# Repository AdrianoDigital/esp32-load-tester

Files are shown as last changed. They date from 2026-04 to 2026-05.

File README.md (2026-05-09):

# esp32-load-tester






A simple, low-cost weight/force measurement device based on an ESP32/ESP8266 and a [load cell](https://en.wikipedia.org/wiki/Load_cell).

It provides:
- A web interface for control and live measurement
- Optional OLED display for local readout
- Simple hardware using inexpensive, widely available components

> ⚠️ Designed for **low-cost, low-accuracy applications** (~±5%, <5 Hz sampling rate)

---

## 📸 Overview

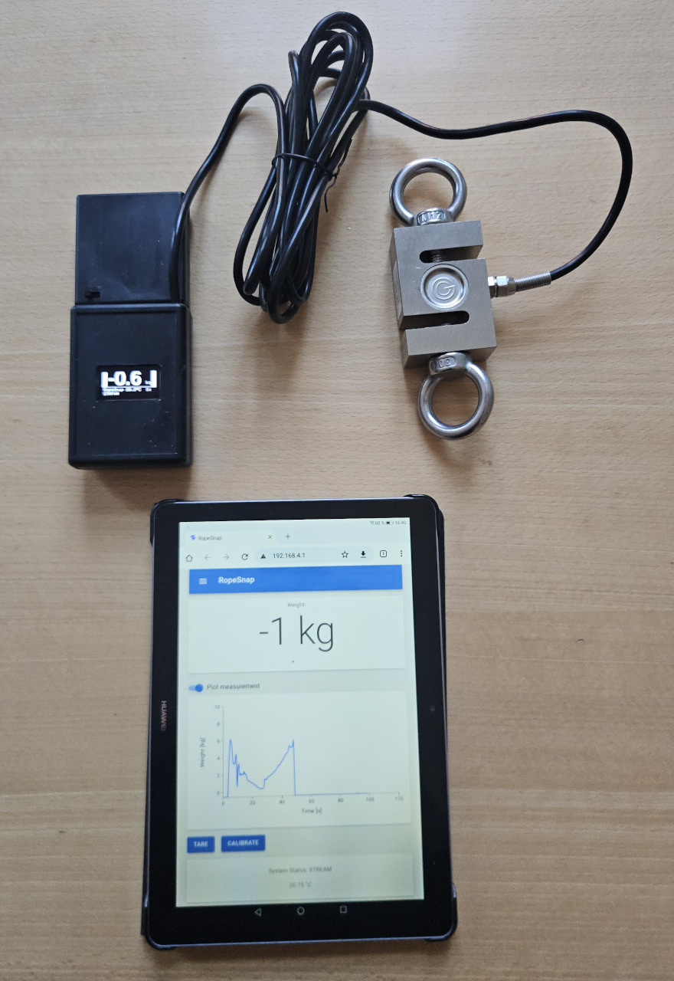
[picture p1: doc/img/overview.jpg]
Device overview


---

## ✨ Features

- Works with a wide range of load cells (grams → tons)
- Wi-Fi access point (no external network required)
- Web-based UI (phone, tablet, desktop)
- Live graph visualization
- QR code for easy connection
- Optional:
  - OLED display
  - Temperature sensor

---

## 🧰 Applications

Suitable for **slow-changing, low-accuracy measurements**, such as:

- Simple tensile strength testing
- Hanging scales
- Simple force measurement

### Example: Tensile Strength Tester

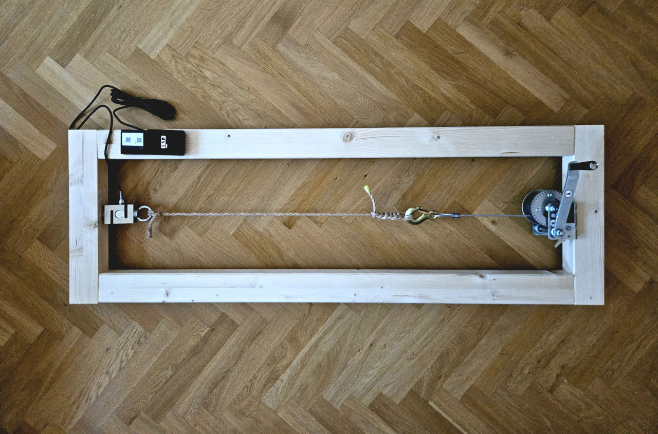
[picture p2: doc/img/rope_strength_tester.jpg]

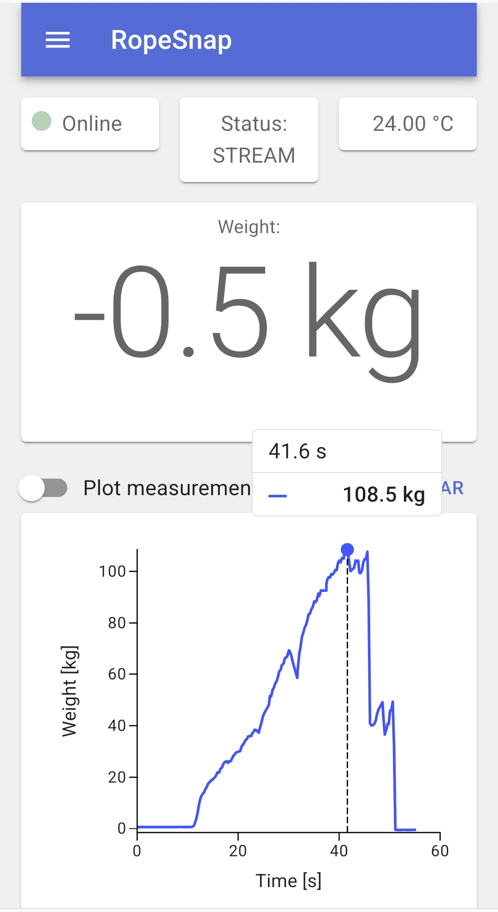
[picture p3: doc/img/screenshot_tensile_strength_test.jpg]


---

## 🧠 System Overview

- Measurement via load cell (Wheatstone bridge) + HX711 ADC 
- Controlled by ESP32 / ESP8266
- Embedded web server provides:
  - REST API
  - Server-Sent Events (SSE)
  - Static file server (compiled React application)
- Client side:
  - React application
  - Rendering with Material Design

**Connectivity:**
- Device creates its own Wi-Fi network
- Wi-Fi protected by WPA2-PSK, password set at build-time
- Wi-Fi QR code is generated for ease of connecting
- Up to 4 clients supported
- Access via: http://192.168.4.1/

**UI behavior:**
- Real-time graph plotting
- SSE-based updates
- Offline detection via watchdog



---

## 🔩 Hardware

### Parts List

|Count|Item|Example|Cost|
|-:|-|-|-:|
|1|Load cell|500 kg|~30 €|
|2|Eye bolts|M12|~6 €|
|1|HX711 ADC||~1 €|
|1|ESP32 dev board|DevKit C (CP2102)|~7 €|
|1|OLED (optional)|1.3" SH1106 128×64|~3 €|
|1|Temp sensor (optional)|DS18B20|~1 €|
|1|Battery holder|4×AA|~1 €|
|1|Power switch||~1 €|
|2|D-Sub connectors|9-pin|~3 €|
|1|3D-printed case (optional)||~7 €|
|||**Total**|~50–60 €|

---

### 🔌 Wiring

Designed for a standard 38-pin ESP32:

- HX711
  - SCK → GPIO 23
  - DT → GPIO 19
- OLED (I²C)
  - SDA → GPIO 21
  - SCL → GPIO 22
- DS18B20
  - DQ → GPIO 18 (pull-up active in ESP)

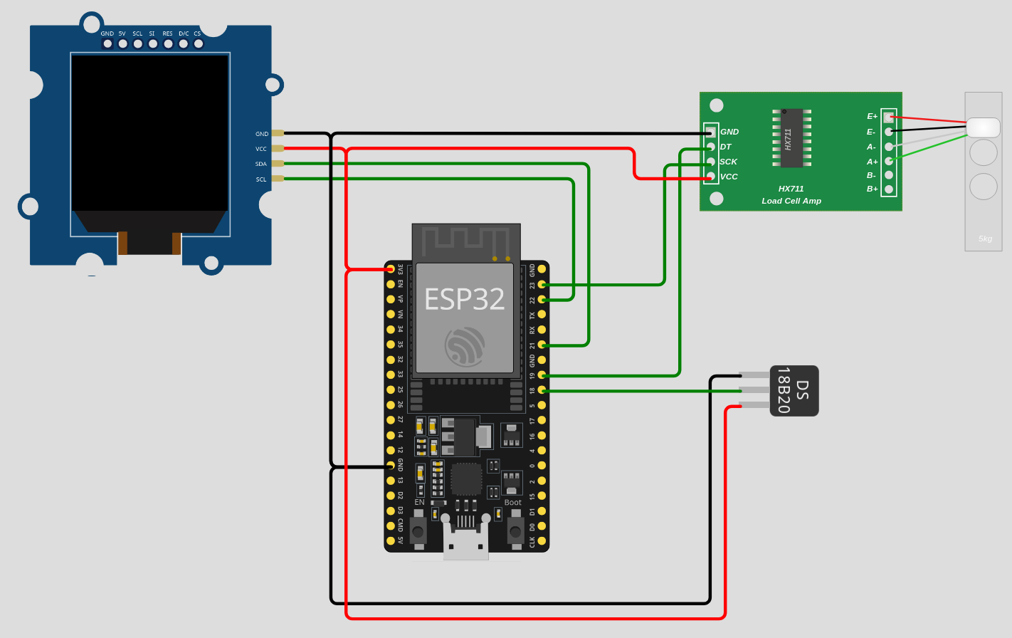
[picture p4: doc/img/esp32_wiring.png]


---

## 💻 Software Setup

### Requirements

- Visual Studio Code
- PlatformIO extension
- Python 3.12+
- npm

### Build Steps

1. Open project in VS Code (PlatformIO auto-detects config)
1. Run custom targets:
   - Generate secrets (Wi-Fi password)
   - Generate Wi-Fi QR code
   - Build web interface
1. Run standard targets:
   - Build filesystem image
   - Upload filesystem
   - Build firmware
   - Upload & monitor

---

## 📦 Web Interface

- Built with Vite + React
  - Built using custom build targets in PlatformIO (s. above)
- Development web-server (instead of ESP32's web server)
- React app uses Material Design
- Communicates with ESP via:
  - REST API
  - Server-Sent Events (SSE)

---

## 🧱 Case

- Designed in FreeCAD  
- File: `mech/case.FCStd`
- STL: `mech/export/case.stl`

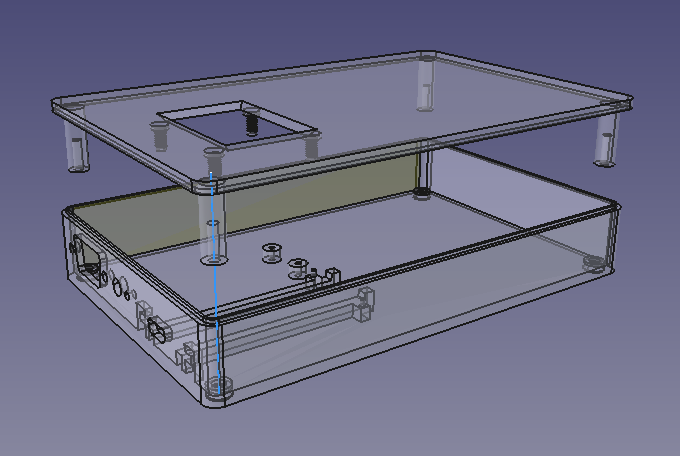
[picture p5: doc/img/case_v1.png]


---

## 📐 3D Design Resources

- [Amphenol D-Sub DE09P064TXLF](https://www.amphenol-cs.com/product/de09p064txlf.html)
- [GOOBAY 10013 switch datasheet](https://cdn-reichelt.de/documents/datenblatt/C200/GOOBAY_10013DB_DE.pdf)
- [Spax 3×12 screw](https://www.spax.com/de-de/p/universalschraube-vollgewinde-senkkopf-kreuzschlitz-z-4cut-yellox.html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)
- [1.3" OLED display](https://www.makershop.de/display/oled/oled-1-3-zoll-weiss/), especially [Datasheet](https://www.makershop.de/download/datasheet-oled-13.pdf)
- [ESP32 3D model (GrabCAD)](https://grabcad.com/library/esp32-38-pines-esp-wroom-32-1)  
  ⚠️ Requires scaling (X=0.976923, Z=1.016000)

---

## 🏗️ Example Build: Tensile Tester



### Shopping List

|Count|Item|Example|Cost|
|-:|-|-|-:|
|1|_esp-load-tester_|_(see above)_|60 €|
|2|Side bars|Wood bar (8 x 6)cm, length 130 cm, softwood sufficient|20 €|
|2|End bars|Wood bar (8 x 6)cm, length 46 cm, softwood sufficient|7 €|
|1|Hand winch, steel cable|E.g. Einhell TC-WI 500|31 €|
|1|Screw for load cell|M12 x 100mm, [carriage bolt](https://en.wikipedia.org/wiki/Carriage_bolt)|1 €|
|2|Screws for winch|Wood screw ⌀ 6 x 80mm|1 €|
|2|Washers for winch|Washer ⌀ 6.4mm x ⌀ 18mm|1 €|
|8|Screws for bars|Wood screw ⌀ 5 x 100mm|1 €|
|||||
|||**Total**|122 €|

---

## ⚠️ Limitations

- Low accuracy (~±5%)
- Low sampling rate (<5 Hz)
- No certified calibration
- Not suitable for safety-critical measurements

---

## 📌 TODO

- [ ] Add cross-platform setup instructions

---

## 📄 License

This project uses a dual-license approach:

### Software
All software components (firmware, web interface) are licensed under the  
**GNU General Public License v3.0 (GPL-3.0)**.

### Hardware
All hardware-related files (CAD models, mechanical designs, schematics) are licensed under the  
**CERN Open Hardware License v2 – Strongly Reciprocal (CERN-OHL-S-2.0)**.

This ensures that:
- Software modifications remain open (GPL-3.0)
- Hardware design improvements must also be shared (CERN-OHL-S)

See the respective license files for details:
- `LICENSE` (GPL-3.0)
- `LICENSE-HARDWARE` (CERN-OHL-S-2.0)

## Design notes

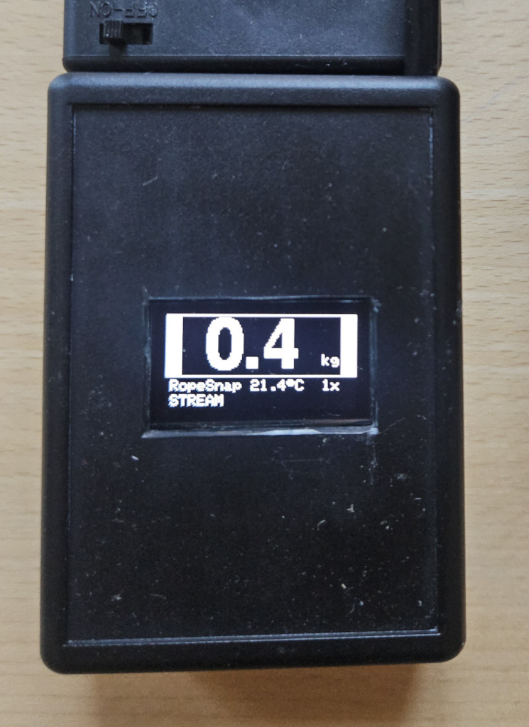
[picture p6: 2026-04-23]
doc/img/device_display.jpg

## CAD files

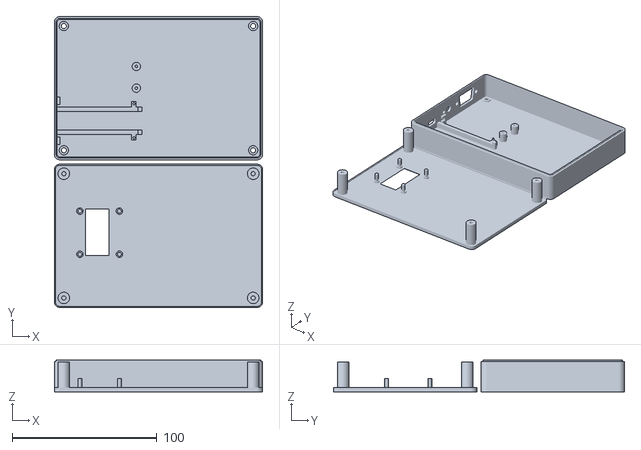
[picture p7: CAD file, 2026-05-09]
mech/export/case.stl
144.0 x 201.0 x 22.0

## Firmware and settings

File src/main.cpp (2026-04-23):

#include <Arduino.h>
#include <ArduinoJson.h>
#include <ESPAsyncWebServer.h>

#include "InfoDisplay.h"
#include "LittleFS.h"
#include "ScaleFSM.h"
#include "ScaleWebAPI.h"
#include "SimpleWifiAP.h"
#include "StreamSSE.h"
#include "TempSens.h"

InfoDisplay info_display("RopeSnap");
AsyncWebServer server(80);
StreamSSE stream(server, "/stream");
SimpleWifiAP wifi_ap(info_display);
ScaleFSM scale_fsm(stream, info_display, HX711_DOUT_PIN, HX711_SCK_PIN);

ScaleWebAPI web_api(server, scale_fsm);
TempSens temp_sens(stream, info_display, DS18B20_PIN);

void setup_little_fs() {
  if (!LittleFS.begin()) {
    Serial.println("Failed to initialize LittleFS system");
    // TODO: proper error state handling
  }
}

void setup_static_file_server() {
  server.serveStatic("/", LittleFS, "/www/").setDefaultFile("index.html");
}

void setup() {
  info_display.setup();
  info_display.boot("Init Serial ...");
  
  Serial.begin(115200);
  Serial.println();
  
  info_display.boot("Init LittleFS ...");
  setup_little_fs();

  info_display.boot("Init temp-sensor ...");
  temp_sens.setup();

  info_display.boot("Init wifi ...");
  wifi_ap.setup();
  info_display.boot("Init web ...");
  web_api.setup();
  setup_static_file_server();

  info_display.boot("Init load cell ...");
  scale_fsm.setup();

  info_display.boot("Finished booting");
  info_display.set_screen(InfoDisplay::SCREEN::MAIN);
}

void loop() {
  scale_fsm.handle_events();
  temp_sens.handle_events();
  wifi_ap.handle_events();
  info_display.handle_events();
}

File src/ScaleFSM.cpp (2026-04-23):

#include "ScaleFSM.h"

ScaleFSM::ScaleFSM(StreamSSE& stream, InfoDisplay& info_display,
                   uint8_t hx711_dout_pin, uint8_t hx711_sck_pin)
    : stream(stream),
      info_display(info_display),
      hx711_dout_pin(hx711_dout_pin),
      hx711_sck_pin(hx711_sck_pin),
      scale(),
      state(t_state::INITIALIZE),
      calib_known_mass(1),
      timeout(),
      stream_state_timeout(STREAM_STATE_PERIOD),
      raw_averager(),
      stream_averager(STREAM_AVERAGE_FACTOR) {}

void ScaleFSM::set_state(t_state new_state) {
  state = new_state;
  String stateStr = get_state_string();
  stream.send("state", stateStr);
  info_display.main_status.set(stateStr);
}

void ScaleFSM::set_error(String new_error) {
  Serial.println(new_error);
  stream.send("fsm_error", new_error);
}

void ScaleFSM::set_measurement(float value) {
  stream.send("weight", value);
  info_display.main_weight.set(value);
}

t_state ScaleFSM::get_state() { return state; }

String ScaleFSM::get_state_string() {
  switch (state) {
    case t_state::INITIALIZE:
      return "INITIALIZE";
    case t_state::READY:
      return "READY";
    case t_state::TARE:
      return "TARE";
    case t_state::CALIB:
      return "CALIB";
    case t_state::STREAM:
      return "STREAM";
    default:
      return "";
  }
}

void ScaleFSM::load_calibration_from_littlefs() {
  String serial_json;
  JsonDocument settings;
  DeserializationError error;

  if (LittleFS.exists(fn_calibration)) {
    File file = LittleFS.open(fn_calibration, "r");
    if (!file) {
      Serial.println("Error: Failed to open '" + String(fn_calibration) +
                     "' for reading.");
      return;
    }
    serial_json = file.readString();
    file.close();
    deserializeJson(settings, serial_json);

    error = deserializeJson(settings, serial_json);
    if (error) {
      Serial.print("Error: deserializeJson() : ");
      Serial.println(error.c_str());
      return;
    }
    if (!settings["offset"].is<long>() || !settings["scale"].is<float>()) {
      Serial.println(
          "Error: Calibration JSON format error (Json: " + serial_json + ")");
      return;
    }
    Serial.println("Loading calibration data");
    scale.set_offset(settings["offset"]);
    scale.set_scale(settings["scale"]);
  }
}

void ScaleFSM::store_calibration_to_littlefs() {
  File file = LittleFS.open(fn_calibration, "w");
  if (!file) {
    Serial.println("Error: Failed to open '" + String(fn_calibration) +
                   "' for writing.");
    return;
  }
  Serial.println("Writing calibration to '" + String(fn_calibration) + "'");
  if (!file.println(get_calibration_json())) {
    Serial.println("Error: Failed to write settings");
    return;
  }
  file.close();
}

String ScaleFSM::get_calibration_json() {
  JsonDocument response;
  String serialized;
  response["offset"] = scale.get_offset();
  response["scale"] = scale.get_scale();
  serializeJson(response, serialized);
  return serialized;
}

void ScaleFSM::set_calibration(const long offset, const float scale_factor) {
  scale.set_offset(offset);
  scale.set_scale(scale_factor);
  store_calibration_to_littlefs();
}

void ScaleFSM::setup() {
  scale.begin(HX711_DOUT_PIN, HX711_SCK_PIN);
  return_to_streaming();
  load_calibration_from_littlefs();
}

bool ScaleFSM::start_tare() {
  if (state == t_state::STREAM) {
    abort_streaming();
  }
  if (state == t_state::READY) {
    Serial.println("Starting tare");
    raw_averager = Averager<long>(TARE_AVERAGE_FACTOR);
    timeout = Timeout(TARE_TIMEOUT);
    set_state(t_state::TARE);
    return true;
  } else {
    return false;
  }
}

bool ScaleFSM::start_calib(float knownMass) {
  if (state == t_state::STREAM) {
    abort_streaming();
  }
  if (state == t_state::READY) {
    calib_known_mass = knownMass;
    Serial.println("Starting calibration");
    raw_averager = Averager<long>(CALIBRATION_AVERAGE_FACTOR);
    timeout = Timeout(CALIB_TIMEOUT);
    set_state(t_state::CALIB);
    return true;
  } else {
    return false;
  }
}

void ScaleFSM::return_to_streaming() {
  if (AUTO_START_STREAMING) {
    stream_averager.clear();
    set_state(t_state::STREAM);
  } else {
    set_state(t_state::READY);
  }
}

bool ScaleFSM::abort_streaming() {
  if (state == t_state::STREAM) {
    set_state(t_state::READY);
    return true;
  } else {
    return false;
  }
}

void ScaleFSM::handle_events() {
  if (stream_state_timeout.is_over()) {
    set_state(state);
    stream_state_timeout.restart();
  }

  switch (state) {
    case t_state::READY:
      break;

    case t_state::TARE:
      if (timeout.is_over()) {
        set_error("Tare timed out");
        return_to_streaming();
      }
      if (scale.is_ready()) {
        raw_averager.add(scale.read());
        if (raw_averager.is_complete()) {
          Serial.printf("Tare done, set offset to %li\n",
                        raw_averager.average());
          scale.set_offset(raw_averager.average());
          store_calibration_to_littlefs();
          return_to_streaming();
        }
      }
      break;

    case t_state::CALIB:
      if (timeout.is_over()) {
        set_error("Calibration timed out");
        return_to_streaming();
      }
      if (scale.is_ready()) {
        raw_averager.add(scale.read() - scale.get_offset());
        if (raw_averager.is_complete()) {
          float scaling_factor =
              (float)raw_averager.average() / calib_known_mass;
          Serial.printf("Calibration done, set scale to %f\n", scaling_factor);
          scale.set_scale(scaling_factor);
          store_calibration_to_littlefs();
          return_to_streaming();
        }
      }
      break;

    case t_state::STREAM:
      if (scale.is_ready()) {
        float value = scale.get_units(1);
        stream_averager.add(value);
        if (stream_averager.is_complete()) {
          set_measurement(stream_averager.average());
          stream_averager.clear();
        }
      }
      break;
    default:
      break;
  }
}

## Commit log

2026-04-23 Add infodisplay to SImpleWifi (not working)
    [main.cpp]
2026-04-23 Replace inter-class poniters by references
    [ScaleFSM.cpp, main.cpp]
2026-04-23 Configure pins in INI
    - Make pins for HX711 and DS18B20 configurable in INI file, so that they can differ per platform (esp32, esp8266)
2026-04-23 Build successful on ESP32
2026-04-23 Fix autostart streaming that blocked tare/calib
    [ScaleFSM.cpp]
2026-04-23 Save calib to LittleFS instead of emulated EEPROM
    - emulated EEPROM didn't work with ESP32, for some reason
    [ScaleFSM.cpp, main.cpp]
2026-04-23 Set ESP32 as default build
2026-04-23 Misc fixes
    - TempSens to stream NaN instead of 999 if reading is incorrect
    - Periodically stream state (REST get at web-if startup no longer needed, safety against modal spinner lockup)
    - Print boot messages to Serial
    [ScaleFSM.cpp]
2026-04-23 Calib: Store as json, add REST functions
    - Store calibration as JSON on the flash (instead of binary format)
    - Add REST api functions to read and set the calibration
2026-04-28 mech: Add a 3d-printable case
    [case.stl]
2026-05-03 Extend README, add tensile strength tester
    Extend readme with more descriptions, part lists,
    pin-out tables, and add example tensile strength tester.
2026-05-03 Add resources used for the case 3d design
2026-05-04 case: Wider bore for screws and stronger poles
    Also, increase case size by 5mm to make room for wider poles
    [case.stl]
2026-05-09 Add internal pull-up for DS18B20 DQ pin
2026-05-09 Fix dimensions of case
    [case.stl]

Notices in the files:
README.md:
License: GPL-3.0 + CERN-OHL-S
